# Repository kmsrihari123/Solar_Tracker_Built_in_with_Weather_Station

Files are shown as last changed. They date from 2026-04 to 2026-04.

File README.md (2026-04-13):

  # SOLAR TRACKER WITH BUILT-IN WEATHER STATION
  
A dual-axis solar tracking system integrated with a real-time weather station, built using Arduino Uno and ESP32.
The Arduino handles physical solar panel tracking using LDR sensors and servo motors with an LCD menu interface. The ESP32 collects atmospheric data (temperature, humidity, pressure) and pushes it to the Arduino IoT Cloud for remote monitoring.

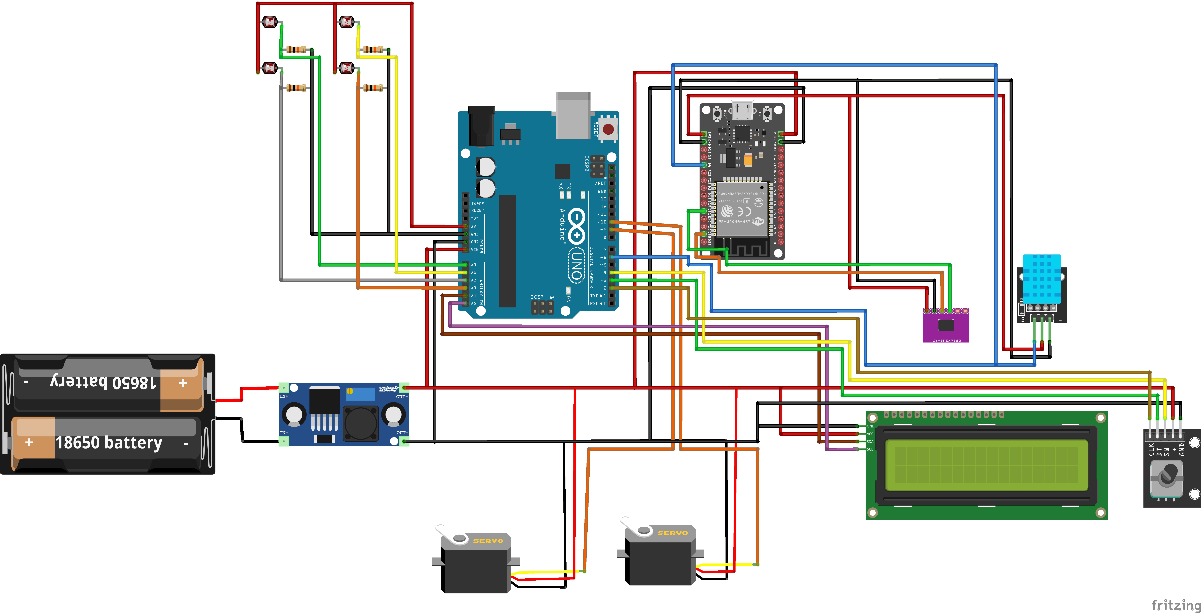
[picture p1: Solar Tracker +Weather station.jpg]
image alt


**SYSTEM ARCHITECTURE**

```
[4x LDR Sensors] ──► [Arduino Uno] ──► [2x Servo Motors]
                          │
                    [I2C LCD 16x2]
                    [Rotary Encoder]
                          │
                     Serial (RX/TX)
                          │
                      [ESP32]
                     /        \
              [DHT11]        [BMP280]
                 \              /
           [Arduino IoT Cloud Dashboard]
```

---

## Hardware Components

| Component | Quantity | Purpose |
|---|---|---|
| Arduino Uno | 1 | Solar tracking controller |
| ESP32 | 1 | Weather station + IoT Cloud |
| LDR (Light Dependent Resistor) | 4 | Sun position sensing |
| Servo Motor (SG90/MG996R) | 2 | Horizontal & Vertical axis |
| I2C LCD 16x2 (0x27) | 1 | Menu display |
| Rotary Encoder (KY-040) | 1 | Menu navigation |
| DHT11 | 1 | Temperature & Humidity |
| BMP280 | 1 | Atmospheric Pressure |
| 18650 Li-ion Battery | 2 | Power supply |
| Buck/Boost Converter | 1 | Voltage regulation |
| 10kΩ Resistors | 4 | LDR voltage dividers |

---
## Pin Configuration

```
ARDUINO UNO
-----------------------------------------
A0          → LDR Top-Left
A1          → LDR Top-Right
A2          → LDR Bottom-Left
A3          → LDR Bottom-Right
D9  (PWM)   → Horizontal Servo Signal
D10 (PWM)   → Vertical Servo Signal
D2          → Rotary Encoder CLK
D3          → Rotary Encoder DT
D4          → Rotary Encoder SW (Button)
D6          → DHT11 Data (local)
A4  (SDA)   → LCD I2C SDA
A5  (SCL)   → LCD I2C SCL
RX0         → ESP32 TX
TX1         → ESP32 RX
5V          → LCD VCC, Encoder VCC
GND         → LCD GND, Encoder GND

ESP32
-----------------------------------------
GPIO 4      → DHT11 Data
GPIO 21     → BMP280 SDA
GPIO 22     → BMP280 SCL
TX          → Arduino RX0
RX          → Arduino TX1
3.3V        → BMP280 VCC, DHT11 VCC
GND         → BMP280 GND, DHT11 GND

POWER
-----------------------------------------
2x 18650    → Buck/Boost Converter IN
Converter   → Arduino VIN + Servo Power
```
## LIBRARIES USED

### Arduino Uno
- `Servo.h` *(built-in)*
- `Wire.h` *(built-in)*
- `LiquidCrystal_I2C` by Frank de Brabander
- `Encoder` by Paul Stoffregen
- `DHT sensor library` by Adafruit

### ESP32
- `ArduinoIoTCloud`
- `Arduino_ConnectionHandler`
- `Adafruit BMP280 Library`
- `DHT sensor library` by Adafruit

---

## FEATURES

- **Dual-axis LDR tracking** — 4 LDRs compute sun direction, servos auto-align panel
- **Sun Time Presets** — Manual preset positions: Morning, Near Noon, Afternoon, Evening, Night
- **Rotary Encoder Menu** — Navigate modes and settings via I2C LCD
- **Weather Display** — Real-time temperature, humidity, pressure on LCD
- **IoT Cloud Dashboard** — ESP32 streams sensor data to Arduino Cloud remotely
- **18650 Battery Powered** — Portable, regulated via buck/boost converter

---

## HOW IT WORKS

1. Four LDRs are positioned at the corners of the solar panel
2. Arduino reads analog values and computes brightness difference between top/bottom and left/right pairs
3. If the difference exceeds a tolerance threshold, the corresponding servo adjusts by 1°
4. ESP32 independently reads DHT11 and BMP280 every 2 seconds and sends data to Arduino IoT Cloud
5. The LCD menu (rotary encoder controlled) lets you switch between tracking mode, weather data, and manual sun time presets

---

## SETUP INSTRUCTIONS

1. Upload `arduino_solar_tracker.ino` to Arduino Uno using Arduino IDE
2. Create an Arduino IoT Cloud account and set up a Thing with variables: `tempertature`, `humidity`, `pressure`
3. Download the generated `thingProperties.h` and place it in the `esp32_weather_station/` folder
4. Upload `esp32_weather_station.ino` to ESP32
5. Connect ESP32 TX → Arduino RX and ESP32 RX → Arduino TX
6. Power the system via 18650 batteries through the buck/boost converter

---

### Made by Sri Hari

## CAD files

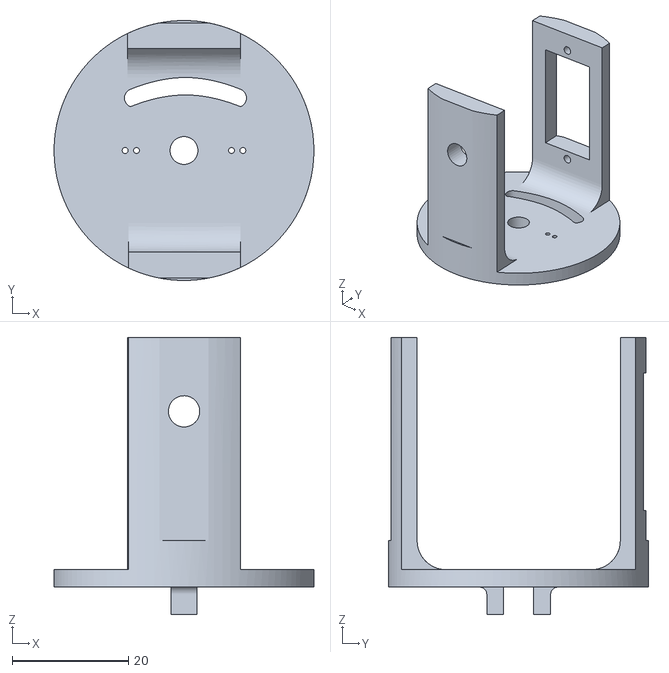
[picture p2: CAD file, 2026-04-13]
CAD Model/Middle Section.stl
44.8 x 44.8 x 47.7

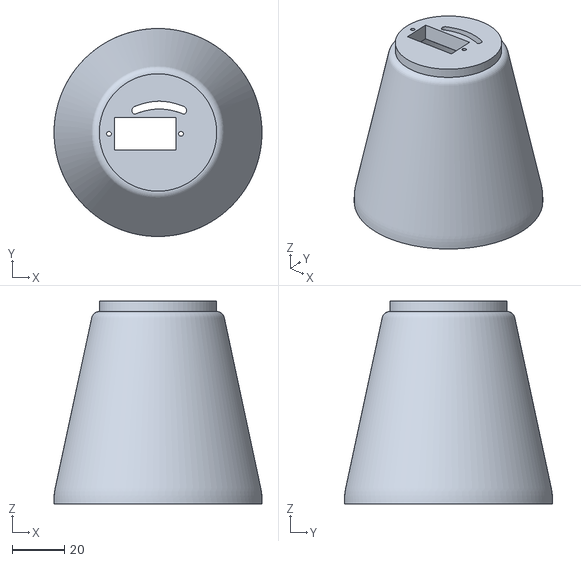
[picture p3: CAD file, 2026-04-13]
Tracker Base.stl
80.0 x 80.0 x 78.0

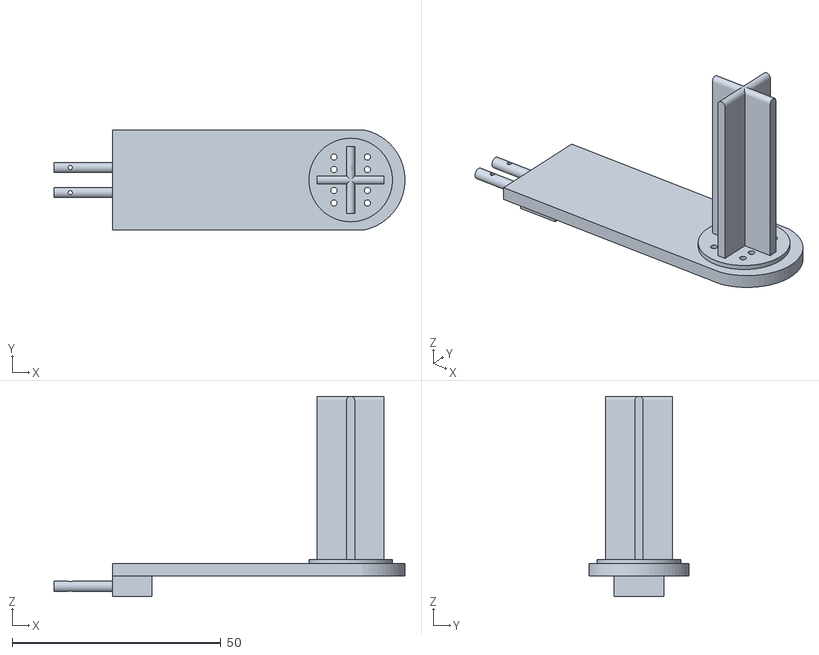
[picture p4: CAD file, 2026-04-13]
LDR Holder.stl
84.0 x 24.0 x 48.0

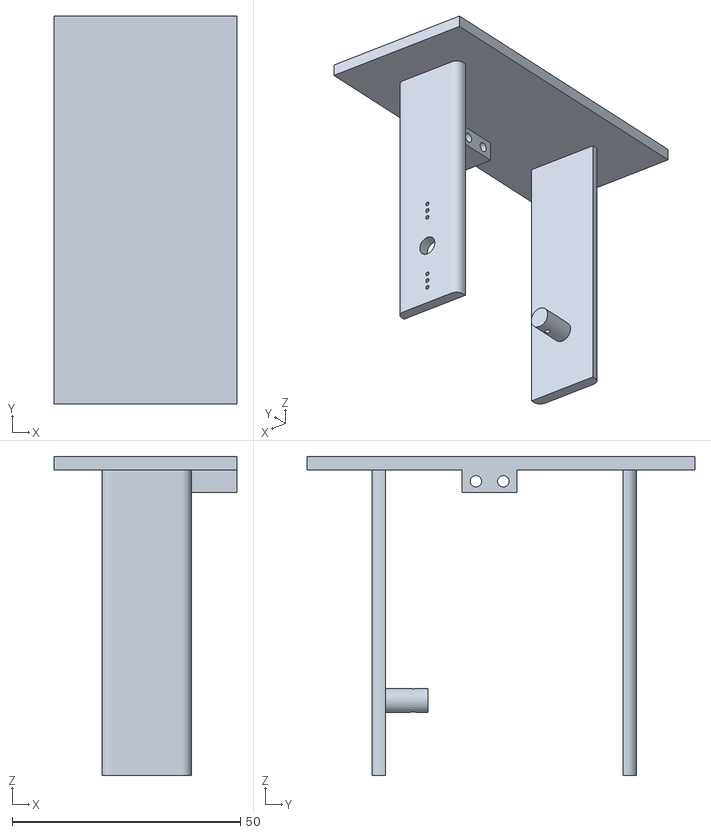
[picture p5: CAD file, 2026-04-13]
Panel Holder.stl
40.0 x 85.0 x 70.0

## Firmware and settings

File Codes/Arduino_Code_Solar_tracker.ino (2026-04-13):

#include <Servo.h>
#include <Wire.h>
#include <LiquidCrystal_I2C.h>
#include <Encoder.h>
#include <DHT.h>  // DHT library

// ================= HARDWARE =================
Servo horizontal;
Servo vertical;

LiquidCrystal_I2C lcd(0x27,16,2);
Encoder knob(2,3);
#define SW 4

// ===== DHT SENSOR =====
#define DHTPIN 6
#define DHTTYPE DHT11
DHT dht(DHTPIN, DHTTYPE);

// ===== TELEMETRY FROM ESP32 =====
float temp = 0;
float hum = 0;
String serialBuffer = "";

// LDR pins
#define TL A0
#define TR A1
#define BL A2
#define BR A3

// Servo positions
int posH = 90;
int posV = 90;

// Limits
const int H_MIN = 5;
const int H_MAX = 175;
const int V_MIN = 5;
const int V_MAX = 175;

const int tolerance = 50;

// ================= MODES =================
enum Mode { SENSOR, TELEMETRY };
Mode currentMode = SENSOR;

// ================= MENU =================
enum MenuLevel { LEVEL_MAIN, LEVEL_TRACKING, LEVEL_WEATHER, LEVEL_SUNTIME };
MenuLevel level = LEVEL_MAIN;

int menuIndex = 0;
long lastPosition = -999;

// ================= SUN TIME =================
enum SunTime { MORNING, NEAR_NOON, AFTERNOON, EVENING, NIGHT };
SunTime sunTime = MORNING;

const char* sunTimeNames[] = {"Morning","Near Noon","Afternoon","Evening","Night"};

int sunPosH[] = {20, 90, 120, 180, 70};
int sunPosV[] = {40,70, 90,  60,  50};

void adjustPanelForSunTime() {
  posH = sunPosH[sunTime];
  posV = sunPosV[sunTime];
  horizontal.write(posH);
  vertical.write(posV);
}

// =====================================================
void setup()
{
  Serial.begin(9600);

  horizontal.attach(9);
  vertical.attach(10);

  horizontal.write(posH);
  vertical.write(posV);

  lcd.init();
  lcd.backlight();

  pinMode(SW, INPUT_PULLUP);

  dht.begin();  // Initialize DHT11

  lcd.setCursor(0,0);
  lcd.print("Solar Tracker");
  lcd.setCursor(0,1);
  lcd.print("Starting...");
  delay(1500);

  drawScreen();
}

////////////////////////////////////////////////////////
// ================= SERIAL RECEIVE ==================
////////////////////////////////////////////////////////
void readTelemetry() {
  if (Serial.available()) {
    String line = Serial.readStringUntil('\n');
    parseData(line);
  }
}

void parseData(String data)
{
  int tIndex = data.indexOf("T:");
  int hIndex = data.indexOf(",H:");

  if(tIndex!=-1 && hIndex!=-1)
  {
    temp  = data.substring(tIndex+2, hIndex).toFloat();
    hum   = data.substring(hIndex+3).toFloat();
  }
}

////////////////////////////////////////////////////////
// ================= TRACKING ==================
////////////////////////////////////////////////////////
void runLDRTracking()
{
  int tl = analogRead(TL);
  int tr = analogRead(TR);
  int bl = analogRead(BL);
  int br = analogRead(BR);

  int topAvg    = (tl + tr) / 2;
  int bottomAvg = (bl + br) / 2;
  int leftAvg   = (tl + bl) / 2;
  int rightAvg  = (tr + br) / 2;

  int diffV = topAvg - bottomAvg;
  int diffH = leftAvg - rightAvg;

  if (abs(diffH) > tolerance)
  {
    //if (diffH > 0 && posH > H_MIN) posH--;
    //else if (diffH < 0 && posH < H_MAX) posH++;
    if (diffH > 0 && posH < H_MAX) posH++;   // swapped
    else if (diffH < 0 && posH > H_MIN) posH--; // swapped
    horizontal.write(posH);
  }

  if (abs(diffV) > tolerance)
  {
    if (diffV > 0 && posV < V_MAX) posV++;
    else if (diffV < 0 && posV > V_MIN) posV--;
    vertical.write(posV);
  }
}

////////////////////////////////////////////////////////
// ================= LOOP ==================
////////////////////////////////////////////////////////
void loop()
{
  readTelemetry();     // ALWAYS read ESP32
  readEncoder();

  if(currentMode == SENSOR)
    runLDRTracking();

  // Read DHT only if weather menu active
  if(level == LEVEL_WEATHER)
  {
    temp = dht.readTemperature();
    hum  = dht.readHumidity();
  }

  // Update sun panel if in sun time menu
  if(level == LEVEL_SUNTIME)
    adjustPanelForSunTime();

  delay(40);
}

////////////////////////////////////////////////////////
// ================= ENCODER ==================
////////////////////////////////////////////////////////
void readEncoder()
{
  long newPos = knob.read()/4;

  if (newPos != lastPosition)
  {
    if (newPos > lastPosition) menuIndex++;
    else menuIndex--;

    if (menuIndex < 0) menuIndex = 0;

    if(level == LEVEL_MAIN && menuIndex > 1) menuIndex = 1;
    if(level == LEVEL_TRACKING && menuIndex > 2) menuIndex = 2;
    if(level == LEVEL_WEATHER && menuIndex > 2) menuIndex = 2;
    if(level == LEVEL_SUNTIME && menuIndex > 5) menuIndex = 5; // 5 options: Morning→Night→Back

    lastPosition = newPos;
    drawScreen();
  }

  if(digitalRead(SW)==LOW)
  {
    delay(180);
    handleClick();
    drawScreen();
  }
}

////////////////////////////////////////////////////////
// ================= CLICK ==================
////////////////////////////////////////////////////////
void handleClick()
{
  if(level == LEVEL_MAIN)
  {
    if(menuIndex == 0){ level = LEVEL_TRACKING; menuIndex = 0; }
    else if(menuIndex == 1){ level = LEVEL_WEATHER; menuIndex = 0; }
  }

  else if(level == LEVEL_TRACKING)
  {
    if(menuIndex == 0){ level = LEVEL_SUNTIME; menuIndex = 0; currentMode = SENSOR; }
    else if(menuIndex == 1) currentMode = SENSOR;
    else if(menuIndex == 2){ level = LEVEL_MAIN; menuIndex = 0; }
  }

  else if(level == LEVEL_WEATHER)
  {
    if(menuIndex==2){ level = LEVEL_MAIN; menuIndex = 0; }
  }

  else if(level == LEVEL_SUNTIME)
  {
    if(menuIndex==5){ level = LEVEL_MAIN; menuIndex = 0; } // Back to main
    else sunTime = static_cast<SunTime>(menuIndex); // Select sun time
  }
}

////////////////////////////////////////////////////////
// ================= LCD ==================
////////////////////////////////////////////////////////
void drawScreen()
{
  lcd.clear();

  if(level == LEVEL_MAIN)
  {
    lcd.setCursor(0,0);
    lcd.print(menuIndex==0?">Tracking Mode":" Tracking Mode");
    lcd.setCursor(0,1);
    lcd.print(menuIndex==1?">Weather Data":" Weather Data");
  }

  else if(level == LEVEL_TRACKING)
  {
    if(menuIndex==0){
      lcd.setCursor(0,0); lcd.print(">Live Telemetry");
      lcd.setCursor(0,1); lcd.print(" Sun Time");
    }
    else if(menuIndex==1){
      lcd.setCursor(0,0); lcd.print(">Sensor Data");
      lcd.setCursor(0,1); lcd.print(" Back");
    }
    else{
      lcd.setCursor(0,0); lcd.print(">Back");
      lcd.setCursor(0,1); lcd.print(" ");
    }
  }

  else if(level == LEVEL_WEATHER)
  {
    lcd.setCursor(0,0);
    if(menuIndex==0){
      lcd.print(">Temp:");
      lcd.print(temp,1); lcd.print((char)223); lcd.print("C");
    }
    else if(menuIndex==1){
      lcd.print(">Humidity:");
      lcd.print(hum,1); lcd.print("%");
    }
    else lcd.print(">Back");
    lcd.setCursor(0,1); lcd.print("                   ");
  }

  else if(level == LEVEL_SUNTIME)
  {
    if(menuIndex<5){
      lcd.setCursor(0,0);
      lcd.print(">");
      lcd.print(sunTimeNames[menuIndex]);
      lcd.setCursor(0,1);
      lcd.print("Adjusting Panel...");
    } else {
      lcd.setCursor(0,0);
      lcd.print(">Back");
      lcd.setCursor(0,1); lcd.print(" ");
    }
  }
}

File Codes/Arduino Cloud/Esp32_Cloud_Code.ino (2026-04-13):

#include "arduino_secrets.h"
#include "thingProperties.h"
#include <Wire.h>
#include <Adafruit_BMP280.h>
#include <DHT.h>

// --- DHT11 setup ---
#define DHTPIN 4
#define DHTTYPE DHT11
DHT dht(DHTPIN, DHTTYPE);

// --- BMP280 setup ---
Adafruit_BMP280 bmp; // I2C

void setup() {
  Serial.begin(9600); // For Arduino Uno communication
  delay(1500);

  // Initialize IoT Cloud
  initProperties();
  ArduinoCloud.begin(ArduinoIoTPreferredConnection);

  setDebugMessageLevel(2);
  ArduinoCloud.printDebugInfo();

  // Initialize sensors
  dht.begin();
  Wire.begin(21, 22); // SDA=21, SCL=22

  if (!bmp.begin(0x76)) {   // Try 0x77 if needed
    Serial.println("Could not find BMP280 sensor!");
    while (1);
  }
}

void loop() {
  ArduinoCloud.update();

  // --- DHT11 readings ---
  float temp = dht.readTemperature();
  float hum  = dht.readHumidity();

  if (isnan(temp) || isnan(hum)) {
    temp = 0;
    hum  = 0;
  }

  // --- BMP280 readings ---
  float pres = bmp.readPressure() / 100.0F; // hPa
  if (isnan(pres)) pres = 0;

  // --- Assign to Cloud variables ---
  tempertature = (int)temp;  // matches your Cloud variable type
  humidity     = (int)hum;
  pressure     = pres;

  // --- Send to Arduino Uno ---
  // Format: T:xx.x,H:yy.y,P:zzz.z\n
  Serial.print("T:");
  Serial.print(temp, 1);
  Serial.print(",H:");
  Serial.print(hum, 1);
  Serial.print(",P:");
  Serial.println(pres, 1);

  // Debug print to Cloud serial monitor
  Serial.print("Temp: "); Serial.print(temp); Serial.print(" °C, ");
  Serial.print("Humidity: "); Serial.print(hum); Serial.print(" %, ");
  Serial.print("Pressure: "); Serial.print(pres); Serial.println(" hPa");

  delay(2000); // 2s delay for sensor reading and transmission
}

// --- Cloud variable callbacks ---
void onTempertatureChange() {}
void onPressureChange() {}
void onHumidityChange() {}

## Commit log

2026-04-13 Add Esp32 Cloud Code file
2026-04-13 Rename Solar Tracker +Weather station.jpg to Circuit Diagram/Solar Tracker +Weather station.jpg
2026-04-13 Create Circuit_Diagram
2026-04-13 Rename Middle Section.stl to CAD Model/Middle Section.stl
    [Middle Section.stl]
2026-04-13 Update README with pin configuration for Arduino and ESP32
    Added pin configuration details for Arduino Uno and ESP32.
